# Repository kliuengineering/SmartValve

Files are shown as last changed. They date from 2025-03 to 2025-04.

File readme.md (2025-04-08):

# Smart Valve Shield for FRDM-K66F
- Authours
    - Amir
    - Kevin
    - Toan

## Preliminary Product Rendering
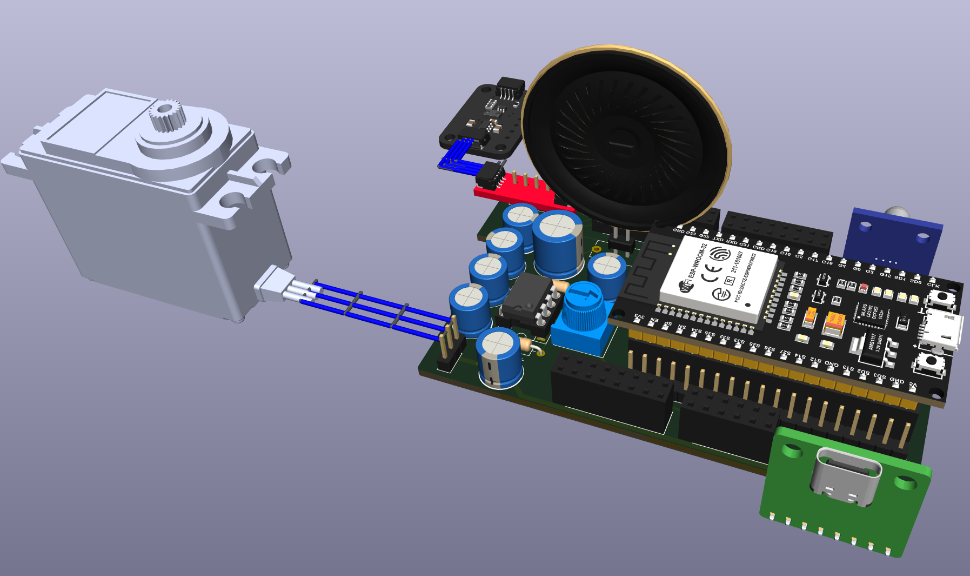
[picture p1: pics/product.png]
ProductImage


## Peripherals On the Shield
**Note: refer to the detailed BOM for specific components.**
1. USB-C power input
2. ESP32S module (38 pins)
3. Class AB amplifier
4. RGB LED module
5. Pressure sensor Qwiic adapter
6. Header pins for servo motor
7. Various pin sockets
8. Various passive components

## Hardware
The design is simple - we want to maximize the real estate of the shield so it becomes a sandbox tool for education purposes. The project about SmartValve is just a simple example of showing you its use case for education. To be fair - K66F is a development platform and is naive for commercial implementations.

### Circuits
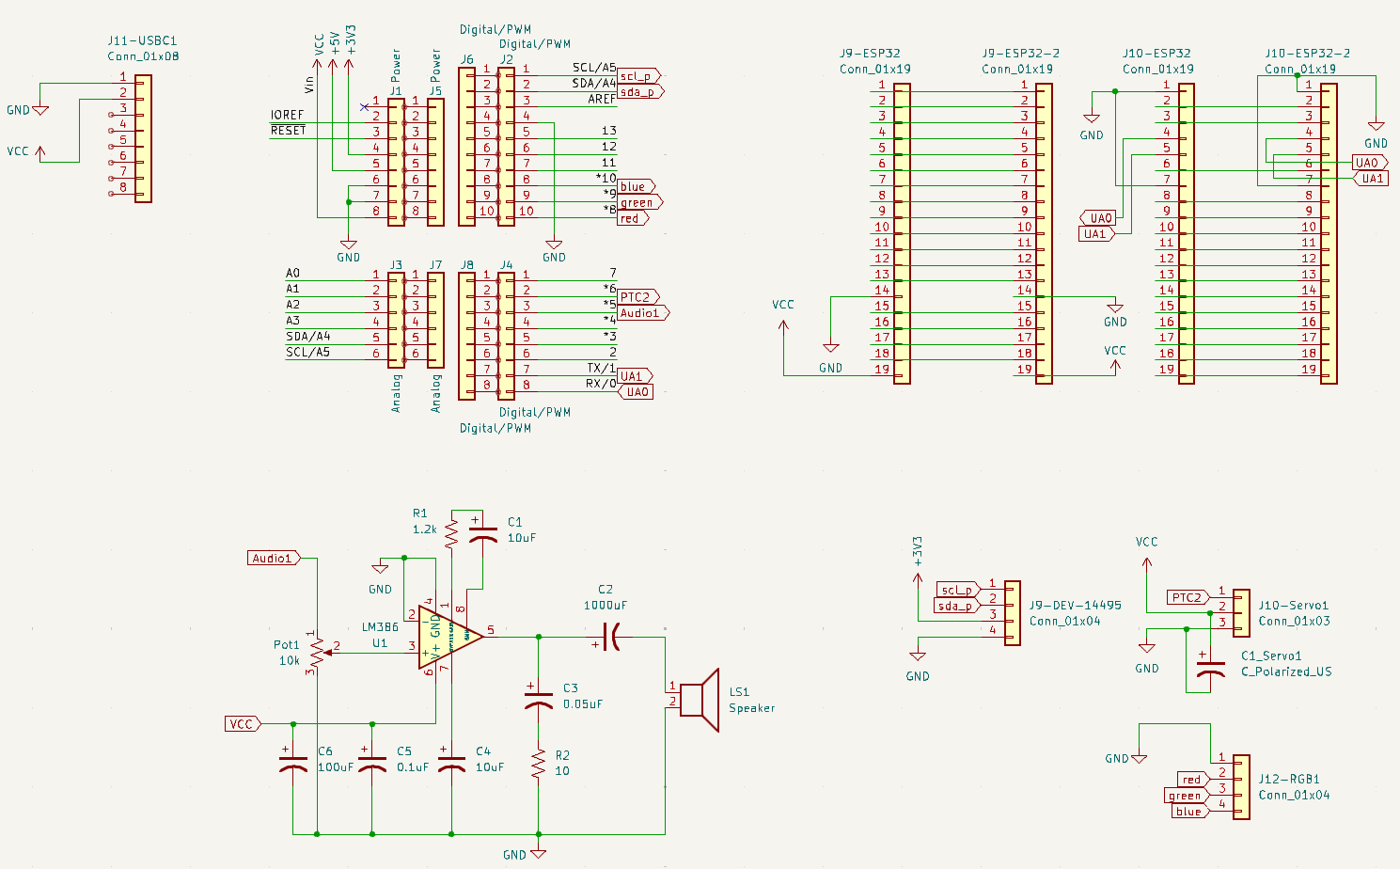
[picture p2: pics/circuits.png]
Circuits


### Routing
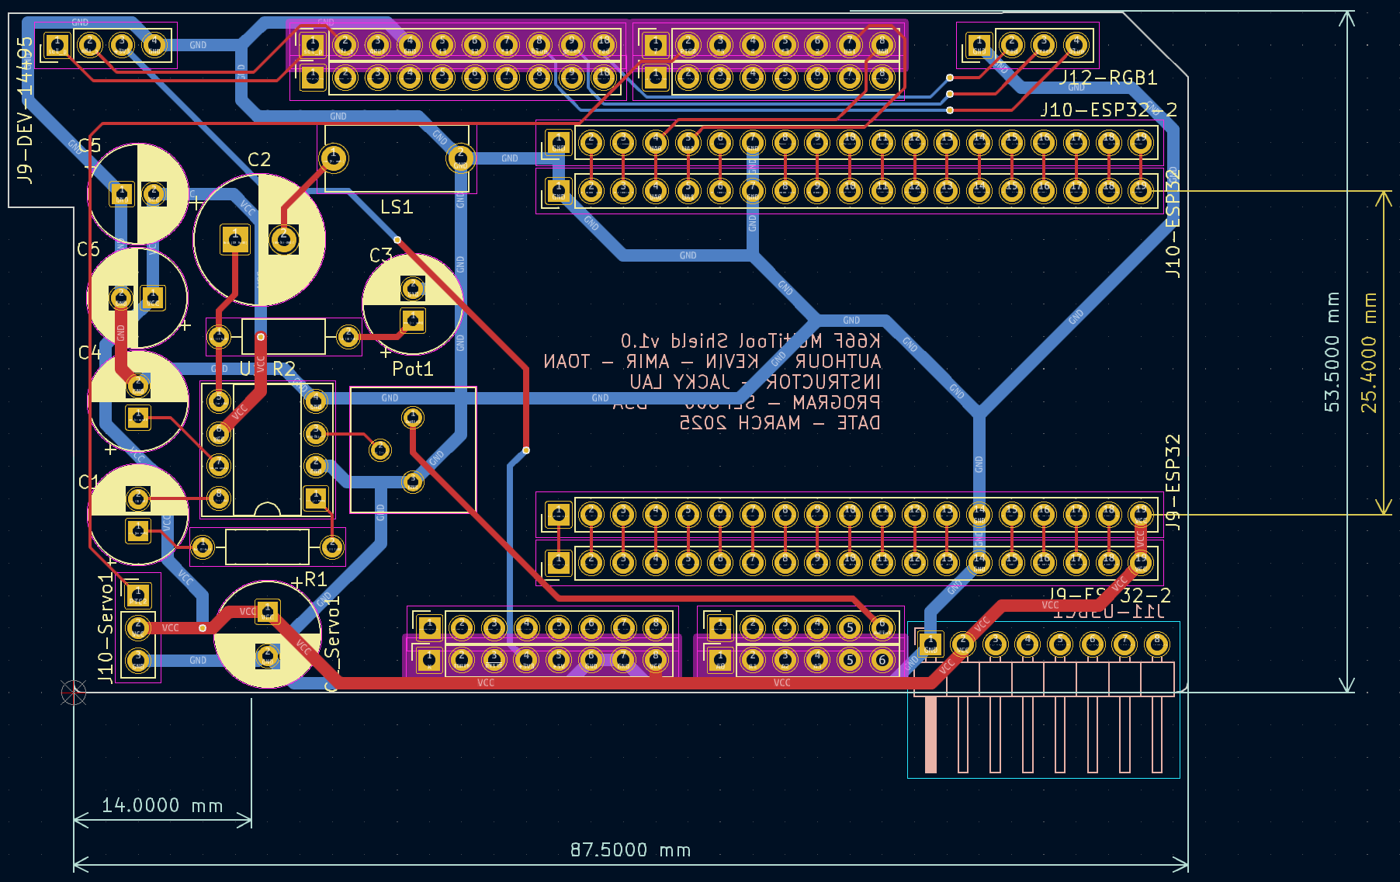
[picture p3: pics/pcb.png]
Routing


## Software

### Installations
1. If you are using Windows, then your machine may require an USB driver for the ESP32 MCU. You can download it here [USB Driver for Windows](Tools/CP210x_Universal_Windows_Driver.zip)

2. Follow the [ESP32 Markdown Documentation](./ESPServer/espserver.md) for server-side details.

### Data Logging Interface
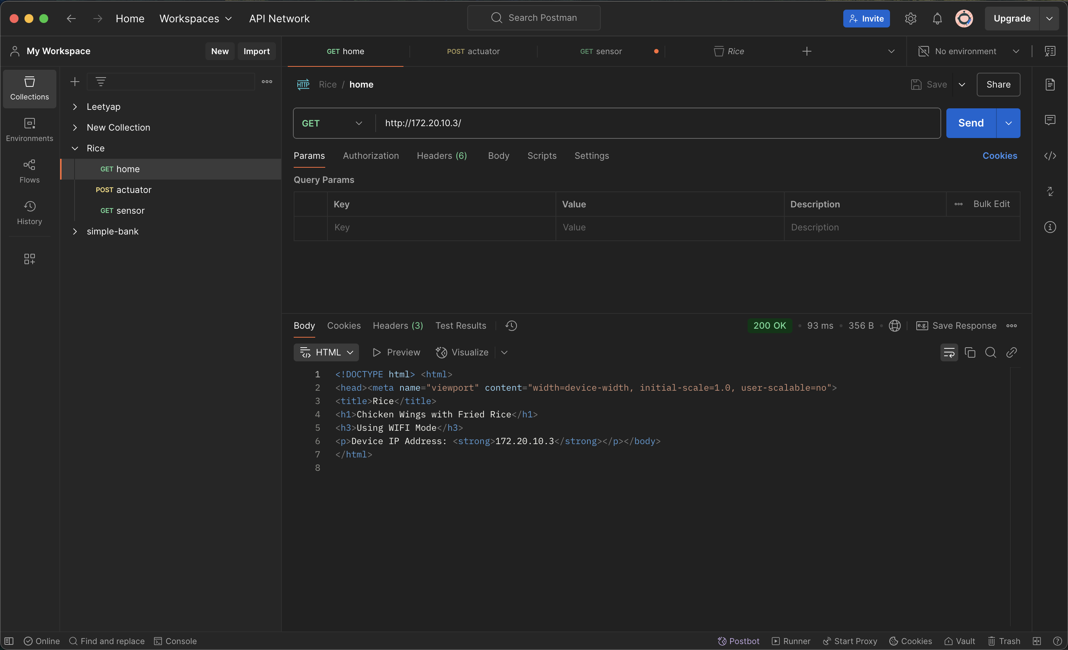
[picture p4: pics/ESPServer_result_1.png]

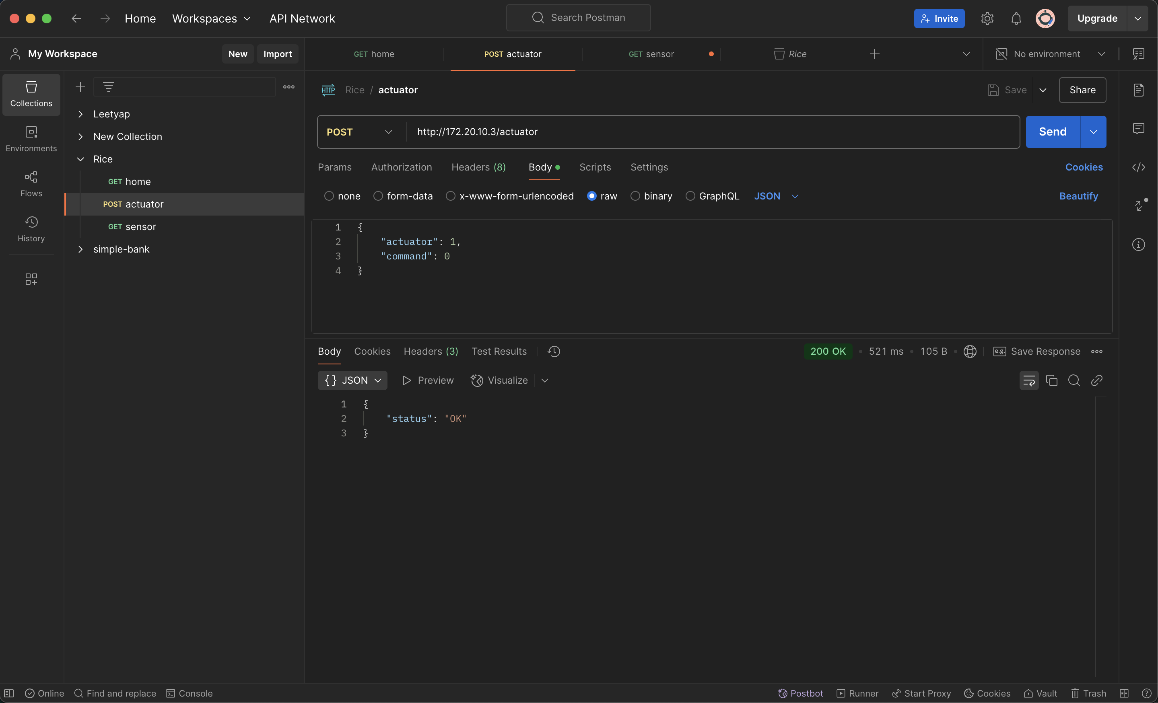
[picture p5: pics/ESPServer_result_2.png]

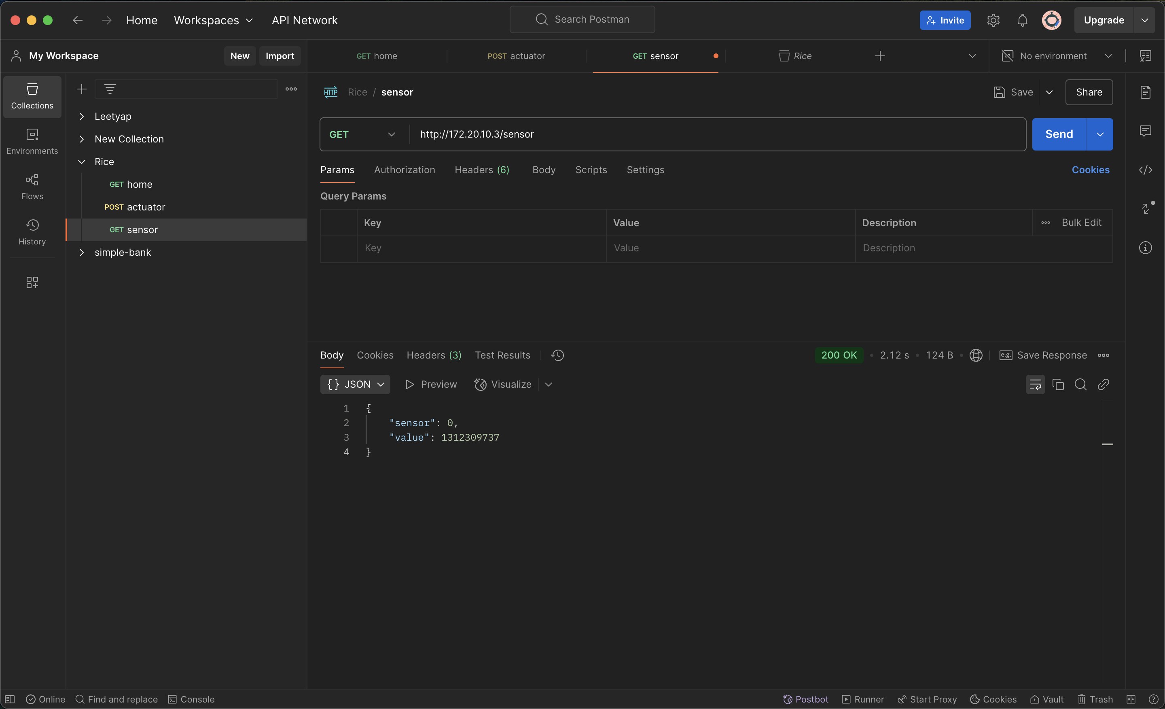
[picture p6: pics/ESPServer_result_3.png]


## Future Work
1. Exploring radio-frequency applications.
2. Implementing TinyML on ESP to carry out more mature edge computing.

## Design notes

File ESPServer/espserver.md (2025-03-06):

## ESP32 server

It acts like a bridge between clients and the K66F

## Hardware setup

#### Set up ESP32

1. Download and install Arduino IDE
2. Go to `Board Manager` -> install `esp32 by Espressif Systems`
3. Upload `espserver.ino` under ESPServer folder into the ESP32

#### Set up K66F

1. Open `Keil IDE`
2. Create a new project with an empty mbedOS project.
3. Copy `frdmk66.example.cpp` into `main.cpp`
4. Build the project into binary file
5. Drag and drop the binary file into the K66F

#### Set up hardware for both ESP32 and K66F (hardware)

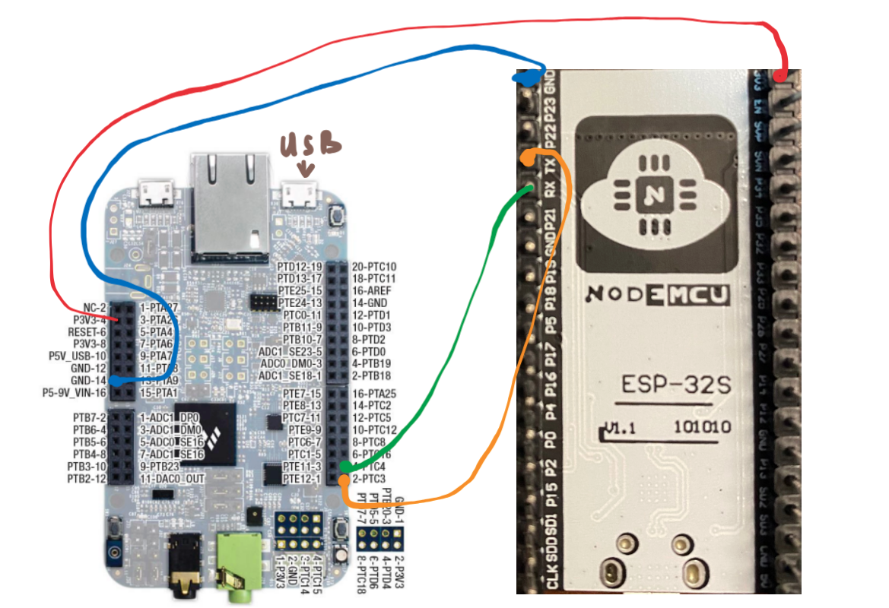
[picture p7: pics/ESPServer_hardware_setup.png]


#### Set up hardware for both ESP32 and K66F (software)

1. Connect K66F with your computer using USB cable
2. run

```bash
ls /dev/cu.* # or do whatever to find the port for K66F on your computer
screen /dev/cu.tty-14031 # dude, this port is mine, so put yours in here

Please press Enter to continue... # this is what we should see, so press Enter
```

3. This step is important, press EN button on ESP32 (maybe the RESET button). At the same time, we also have to turn `OFF` and then `ON` the Personal Hotspot on your phone. If you don't see it connecting with your Hotspot, wait for 1 second and repeat, and keep doing so until you see:

```bash
Please press Enter to continue...
K66F - Received ets Jul 29 2019 12:21:46

rst:0x1 (POWERON_RESET),boot:0x13 (SPI_FAST_FLASH_BOOT)
configsip: 0, SPIWP:0xee
clk_drv:0x00,q_d

K66F - Received rv:0x00,d_drv:0x00,cs0_drv:0x00,hd_drv:0x00,wp_drv:0x00
mode:DIO, clock div:1
load:0x3fff0030,len:4916
load:0x40078000,len:1

K66F - Received 64�

ESP - Connecting to tovn

K66F - Received ESP - WiFi Connected! IP Address: 172.20.10.3 # If you don't see this, keep doing step 3 until you see the IP Address. *Note: repeat after 1 or 2 seconds.
ESP - HTTP server started on port 80
```

## API endpoints

#### GET: /ip-address/

Inital request to be sure the ESP32 server is working.

```html
<!DOCTYPE html> <html>
<head><meta name="viewport" content="width=device-width, initial-scale=1.0, user-scalable=no">
<title>Rice</title>
<h1>Chicken Wings with Fried Rice</h1>
<h3>Using WIFI Mode</h3>
<p>Device IP Address: <strong>172.20.10.3</strong></p></body>
</html>
```

#### GET: /ip-address/sensor

Client requests sensor values from K66F via the ESP32 server.

```json
{
  "sensor": 1,
  "value": 12
}
```

#### POST: /ip-address/actuator

Client sends command to actuators attached to K66F via the ESP32 server.

```json
{
  "actuator": 1,
  "command": 0
}
```

## Expected results







```bash
Please press Enter to continue...
Please press Enter to continue...
K66F - Received ets Jul 29 2019 12:21:46

rst:0x1 (POWERON_RESET),boot:0x13 (SPI_FAST_FLASH_BOOT)
configsip: 0, SPIWP:0xee
clk_drv:0x00,q_d

K66F - Received rv:0x00,d_drv:0x00,cs0_drv:0x00,hd_drv:0x00,wp_drv:0x00
mode:DIO, clock div:1
load:0x3fff0030,len:4916
load:0x40078000,len:1

K66F - Received 64�

ESP - Connecting to tovn

K66F - Received ESP - WiFi Connected! IP Address: 172.20.10.3
ESP - HTTP server started on port 80

K66F - SENDDATA command received
K66F - send {"sensor": 0, "value": 1640049856}
K66F - Received SENDDATA

K66F - Received ESP - Received HTTP GET - /sensor

actuator command received
K66F - Received {
    "actuator": 1,
    "command": 0
}ESP - Received HTTP POST - /actuator
```

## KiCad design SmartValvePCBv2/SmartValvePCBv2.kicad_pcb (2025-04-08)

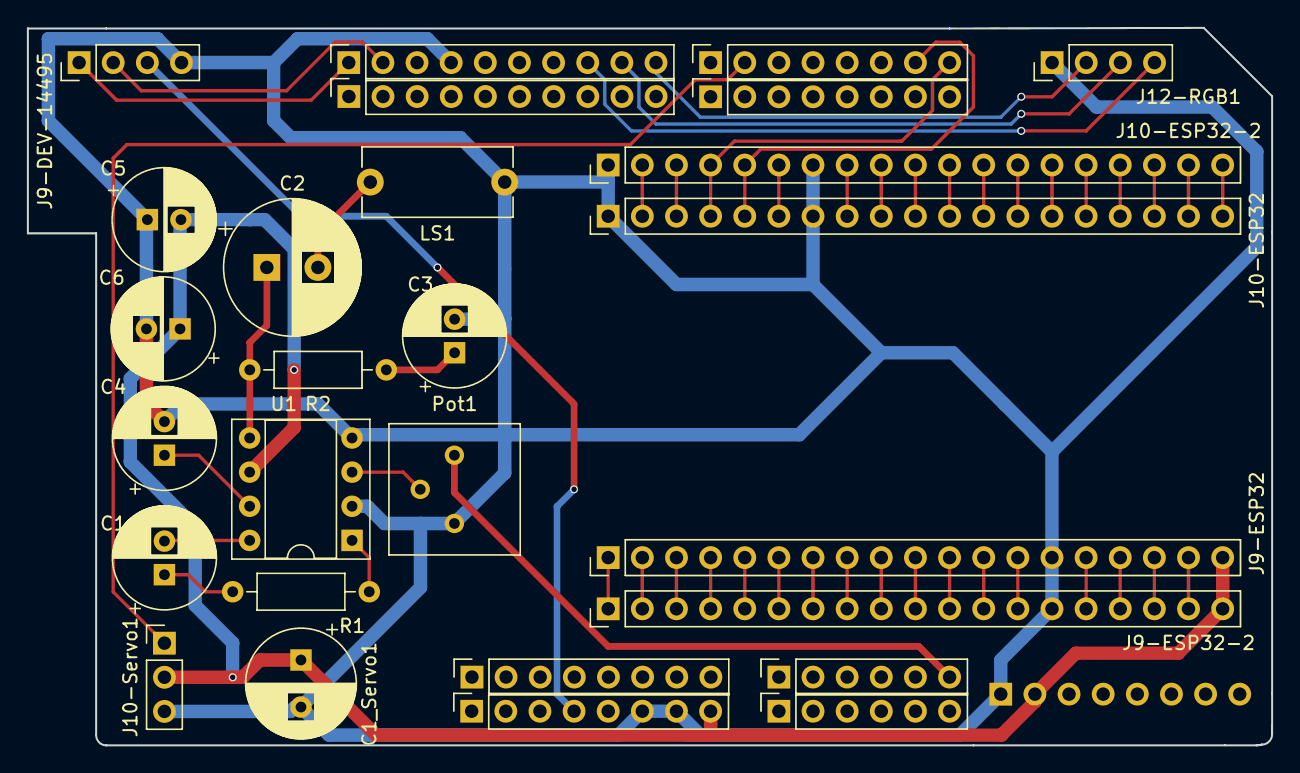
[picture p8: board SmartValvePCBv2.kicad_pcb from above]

Board: 2 copper layers, 92.6 x 53.4 mm, 28 parts (1 on the bottom side), 52 nets.

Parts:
C1, C4: 10uF; CP_Radial_D7.5mm_P2.50mm
C1_Servo1: C_Polarized_US; CP_Radial_D8.0mm_P3.50mm
C2: 470uF; CP_Radial_D10.0mm_P3.80mm
C3: 0.05uF; CP_Radial_D7.5mm_P2.50mm
C5: 0.1uF; CP_Radial_D7.5mm_P2.50mm
C6: 100uF; CP_Radial_D7.5mm_P2.50mm
J1, J5: Power; PinSocket_1x08_P2.54mm_Vertical
J2, J6: Digital/PWM; PinSocket_1x10_P2.54mm_Vertical
J3, J7: Analog; PinSocket_1x06_P2.54mm_Vertical
J4, J8: Digital/PWM; PinSocket_1x08_P2.54mm_Vertical
J9-DEV-14495, J12-RGB1: Conn_01x04; PinHeader_1x04_P2.54mm_Vertical
J9-ESP32, J9-ESP32-2, J10-ESP32, J10-ESP32-2: Conn_01x19; PinHeader_1x19_P2.54mm_Vertical
J10-Servo1: Conn_01x03; PinHeader_1x03_P2.54mm_Vertical
J11-USBC1: Conn_01x08; PinHeader_1x08_P2.54mm_Horizontal
LS1: Speaker; C_Disc_D11.0mm_W5.0mm_P10.00mm
Pot1: 10k; Potentiometer_Bourns_3386P_Vertical
R1: 1.2k; R_Axial_DIN0207_L6.3mm_D2.5mm_P10.16mm_Horizontal
R2: 10; R_Axial_DIN0207_L6.3mm_D2.5mm_P10.16mm_Horizontal
U1: LM386; DIP-8_W7.62mm_Socket

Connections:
+3V3: J1.4, J9-DEV-14495.3
Audio1: J7.6, Pot1.1
GND: C1_Servo1.2, C3.2, C4.2, C5.1, C6.2, J1.6, J1.7, J2.4, J9-DEV-14495.4, J9-ESP32.14, J9-ESP32-2.14, J10-ESP32.1, J10-ESP32.7, J10-ESP32-2.1, J10-ESP32-2.7, J10-Servo1.3, J11-USBC1.1, J12-RGB1.1, LS1.2, Pot1.3, U1.2 (-), U1.4 (GND)
unnamed: C1.1, R1.1
unnamed: C1.2, U1.8 (GAIN)
unnamed: C2.1, R2.1, U1.5
unnamed: C2.2, LS1.1
unnamed: C3.1, R2.2
unnamed: J9-ESP32.1, J9-ESP32-2.1
unnamed: J9-ESP32.2, J9-ESP32-2.2
unnamed: J9-ESP32.3, J9-ESP32-2.3
unnamed: J9-ESP32.4, J9-ESP32-2.4
unnamed: J9-ESP32.5, J9-ESP32-2.5
unnamed: J9-ESP32.6, J9-ESP32-2.6
unnamed: J9-ESP32.7, J9-ESP32-2.7
unnamed: J9-ESP32.8, J9-ESP32-2.8
unnamed: J9-ESP32.9, J9-ESP32-2.9
unnamed: J9-ESP32.10, J9-ESP32-2.10
unnamed: J9-ESP32.11, J9-ESP32-2.11
unnamed: J9-ESP32.12, J9-ESP32-2.12
unnamed: J9-ESP32.13, J9-ESP32-2.13
unnamed: J9-ESP32.15, J9-ESP32-2.15
unnamed: J9-ESP32.16, J9-ESP32-2.16
unnamed: J9-ESP32.17, J9-ESP32-2.17
unnamed: J9-ESP32.18, J9-ESP32-2.18
unnamed: J10-ESP32.2, J10-ESP32-2.2
unnamed: J10-ESP32.3, J10-ESP32-2.3
unnamed: J10-ESP32.6, J10-ESP32-2.6
unnamed: J10-ESP32.8, J10-ESP32-2.8
unnamed: J10-ESP32.9, J10-ESP32-2.9
unnamed: J10-ESP32.10, J10-ESP32-2.10
unnamed: J10-ESP32.11, J10-ESP32-2.11
unnamed: J10-ESP32.12, J10-ESP32-2.12
unnamed: J10-ESP32.13, J10-ESP32-2.13
unnamed: J10-ESP32.14, J10-ESP32-2.14
unnamed: J10-ESP32.15, J10-ESP32-2.15
unnamed: J10-ESP32.16, J10-ESP32-2.16
unnamed: J10-ESP32.17, J10-ESP32-2.17
unnamed: J10-ESP32.18, J10-ESP32-2.18
unnamed: J10-ESP32.19, J10-ESP32-2.19
unnamed: R1.2, U1.1 (GAIN)
unnamed: Pot1.2, U1.3 (+)
unnamed: C4.1, U1.7 (BYPASS)
PTC2: J4.2, J10-Servo1.1
UA0: J4.8, J10-ESP32.4, J10-ESP32-2.4
UA1: J4.7, J10-ESP32.5, J10-ESP32-2.5
VCC: C1_Servo1.1, C5.2, C6.1, J1.8, J9-ESP32.19, J9-ESP32-2.19, J10-Servo1.2, J11-USBC1.2, U1.6 (V+)
blue: J2.8, J12-RGB1.4
green: J2.9, J12-RGB1.3
red: J2.10, J12-RGB1.2
scl_p: J2.1, J9-DEV-14495.1
sda_p: J2.2, J9-DEV-14495.2

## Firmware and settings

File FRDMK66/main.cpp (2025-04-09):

#include "mbed.h"
#include "RGBLed.h"
#include "PressureSensor.h"
#include "ServoMotor.h"

using namespace std::chrono;

// --- Config ---
#define I2C_SDA_PIN PTC11
#define I2C_SCL_PIN PTC10
#define I2C_BAUDRATE 50000U
#define BMP3_I2C_ADDR 0x77
#define UART_TX PTC4
#define UART_RX PTC3
#define UART_BAUD 115200

// --- Interfaces ---
BufferedSerial uart(UART_TX, UART_RX, UART_BAUD);
I2C i2c(I2C_SDA_PIN, I2C_SCL_PIN);

// --- Devices ---
RGBLed led(PTB18, PTB19, PTD0);
PressureSensor sensor(i2c, BMP3_I2C_ADDR);
ServoMotor servo(PTC2);
bool valve_closed = false;

// --- Threads ---
Mutex lock_mutex;
Thread sensorThread;
Thread commsThread;

float pressure_hPa = 0.0f;

// --- Parse JSON command from ESP32 ---
bool parseActuatorCommand(const char* json, int& actuator, int& command) {
    const char* act_key = "\"actuator\"";
    const char* cmd_key = "\"command\"";
    const char* act_ptr = strstr(json, act_key);
    const char* cmd_ptr = strstr(json, cmd_key);
    if (!act_ptr || !cmd_ptr) return false;

    act_ptr = strchr(act_ptr, ':');
    cmd_ptr = strchr(cmd_ptr, ':');
    if (!act_ptr || !cmd_ptr) return false;

    actuator = atoi(++act_ptr);
    command = atoi(++cmd_ptr);

    return true;
}

// --- Read pressure sensor periodically ---
void read_sensor_data() {
    while (true) {
        float pressure = sensor.readPressure();
        lock_mutex.lock();
        pressure_hPa = pressure;
        printf("Pressure: %.2f hPa\n", pressure_hPa);
        lock_mutex.unlock();
        ThisThread::sleep_for(1s);
    }
}

// --- UART Command Handler (from ESP32) ---
void serve_client() {
    char buf[64];
    while (true) {
        if (uart.readable()) {
            uart.read(buf, sizeof(buf));
            buf[sizeof(buf) - 1] = '\0';

            if (strncmp(buf, "SENDDATA", 8) == 0) {
                lock_mutex.lock();
                char response[64];
                int len = sprintf(response, "{\"pressure\":%.2f}", pressure_hPa);
                uart.write(response, len);
                printf("Sent to ESP32: %s\n", response);
                lock_mutex.unlock();
            } 
            else if (strstr(buf, "actuator")) {
                int actuator, command;
                if (parseActuatorCommand(buf, actuator, command)) {
                    if (actuator == 1) {
                        if (command == 1 && !valve_closed) {
                            led.setColor(1.0, 0.0, 0.0);  // Red = Close
                            servo = 45.0f;
                            valve_closed = true;
                            printf("Valve CLOSED by AI command.\n");
                        } else if (command == 0 && valve_closed) {
                            led.setColor(0.0, 1.0, 0.0);  // Green = Open
                            servo = -45.0f;
                            valve_closed = false;
                            printf("Valve OPENED by AI command.\n");
                        }
                    }
                } else {
                    printf("Failed to parse actuator command.\n");
                }
            }
        }
        ThisThread::sleep_for(100ms);
    }
}

// --- Entry Point ---
int main() {
    printf("FRDM-K66 Booting...\n");

    i2c.frequency(I2C_BAUDRATE);
    led.setColor(0.0, 0.0, 0.0);  // LED OFF on boot
    sensor.initialize();

    sensorThread.start(read_sensor_data);
    commsThread.start(serve_client);

    while (true) {
        ThisThread::sleep_for(1s);
    }
}

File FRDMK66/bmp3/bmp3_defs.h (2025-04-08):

/**
* Copyright (c) 2022 Bosch Sensortec GmbH. All rights reserved.
*
* BSD-3-Clause
*
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
* 1. Redistributions of source code must retain the above copyright
*    notice, this list of conditions and the following disclaimer.
*
* 2. Redistributions in binary form must reproduce the above copyright
*    notice, this list of conditions and the following disclaimer in the
*    documentation and/or other materials provided with the distribution.
*
* 3. Neither the name of the copyright holder nor the names of its
*    contributors may be used to endorse or promote products derived from
*    this software without specific prior written permission.
*
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
* @file       bmp3_defs.h
* @date       2022-04-01
* @version    v2.0.6
*
*/

/*! @file bmp3_defs.h
 * @brief Sensor driver for BMP3 sensor */

 #ifndef BMP3_DEFS_H_
 #define BMP3_DEFS_H_
 
 /*! CPP guard */
 #ifdef __cplusplus
 extern "C" {
 #endif
 
 /********************************************************/
 /* header includes */
 #ifdef __KERNEL__
 #include <linux/types.h>
 #include <linux/kernel.h>
 #else
 #include <stdint.h>
 #include <stddef.h>
 #endif
 
 /*************************** Common macros   *****************************/
 
 #if !defined(UINT8_C) && !defined(INT8_C)
 #define INT8_C(x)    S8_C(x)
 #define UINT8_C(x)   U8_C(x)
 #endif
 
 #if !defined(UINT16_C) && !defined(INT16_C)
 #define INT16_C(x)   S16_C(x)
 #define UINT16_C(x)  U16_C(x)
 #endif
 
 #if !defined(INT32_C) && !defined(UINT32_C)
 #define INT32_C(x)   S32_C(x)
 #define UINT32_C(x)  U32_C(x)
 #endif
 
 #if !defined(INT64_C) && !defined(UINT64_C)
 #define INT64_C(x)   S64_C(x)
 #define UINT64_C(x)  U64_C(x)
 #endif
 
 /**@}*/
 /**\name C standard macros */
 #ifndef NULL
 #ifdef __cplusplus
 #define NULL         0
 #else
 #define NULL         ((void *) 0)
 #endif
 #endif
 
 #ifndef TRUE
 #define TRUE         UINT8_C(1)
 #endif
 
 #ifndef FALSE
 #define FALSE        UINT8_C(0)
 #endif
 
 /********************************************************/
 /**\name Compiler switch macros */
 
 #ifndef BMP3_64BIT_COMPENSATION /*< Check if 64bit (using BMP3_64BIT_COMPENSATION) is enabled */
 #ifndef BMP3_FLOAT_COMPENSATION /*< If 64 bit integer data type is not enabled then enable
                                             * BMP3_FLOAT_COMPENSATION */
 #define BMP3_FLOAT_COMPENSATION
 #endif
 #endif
 
 /********************************************************/
 /**\name Macro definitions */
 
 /**
  * BMP3_INTF_RET_TYPE is the read/write interface return type which can be overwritten by the build system.
  */
 #ifndef BMP3_INTF_RET_TYPE
 #define BMP3_INTF_RET_TYPE                      int8_t
 #endif
 
 /**
  * The last error code from read/write interface is stored in the device structure as intf_rslt.
  */
 #ifndef BMP3_INTF_RET_SUCCESS
 #define BMP3_INTF_RET_SUCCESS                   INT8_C(0)
 #endif
 
 /**\name I2C addresses */
 #define BMP3_ADDR_I2C_PRIM                      UINT8_C(0x76)
 #define BMP3_ADDR_I2C_SEC                       UINT8_C(0x77)
 
 /**\name BMP3 chip identifier */
 #define BMP3_CHIP_ID                            UINT8_C(0x50)
 #define BMP390_CHIP_ID                          UINT8_C(0x60)
 
 /**\name BMP3 pressure settling time (micro secs)*/
 #define BMP3_SETTLE_TIME_PRESS                  UINT16_C(392)
 
 /**\name BMP3 temperature settling time (micro secs) */
 #define BMP3_SETTLE_TIME_TEMP                   UINT16_C(313)
 
 /**\name BMP3 adc conversion time (micro secs) */
 #define BMP3_ADC_CONV_TIME                      UINT16_C(2000)
 
 /**\name Register Address */
 #define BMP3_REG_CHIP_ID                        UINT8_C(0x00)
 #define BMP3_REG_ERR                            UINT8_C(0x02)
 #define BMP3_REG_SENS_STATUS                    UINT8_C(0x03)
 #define BMP3_REG_DATA                           UINT8_C(0x04)
 #define BMP3_REG_EVENT                          UINT8_C(0x10)
 #define BMP3_REG_INT_STATUS                     UINT8_C(0x11)
 #define BMP3_REG_FIFO_LENGTH                    UINT8_C(0x12)
 #define BMP3_REG_FIFO_DATA                      UINT8_C(0x14)
 #define BMP3_REG_FIFO_WM                        UINT8_C(0x15)
 #define BMP3_REG_FIFO_CONFIG_1                  UINT8_C(0x17)
 #define BMP3_REG_FIFO_CONFIG_2                  UINT8_C(0x18)
 #define BMP3_REG_INT_CTRL                       UINT8_C(0x19)
 #define BMP3_REG_IF_CONF                        UINT8_C(0x1A)
 #define BMP3_REG_PWR_CTRL                       UINT8_C(0x1B)
 #define BMP3_REG_OSR                            UINT8_C(0X1C)
 #define BMP3_REG_ODR                            UINT8_C(0x1D)
 #define BMP3_REG_CONFIG                         UINT8_C(0x1F)
 #define BMP3_REG_CALIB_DATA                     UINT8_C(0x31)
 #define BMP3_REG_CMD                            UINT8_C(0x7E)
 
 /**\name Error status macros */
 #define BMP3_ERR_FATAL                          UINT8_C(0x01)
 #define BMP3_ERR_CMD                            UINT8_C(0x02)
 #define BMP3_ERR_CONF                           UINT8_C(0x04)
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

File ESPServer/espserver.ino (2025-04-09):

#include <WiFi.h>
#include <WebServer.h>
#include <ArduinoJson.h>
#include "NeuralNetwork.h"

// WiFi Credentials
const char* ssid = "Amir";
const char* password = "gotthat1";

// IP Configuration
IPAddress local_IP(172, 20, 10, 3);
IPAddress gateway(172, 20, 10, 1);
IPAddress subnet(255, 255, 255, 0);

// Web Server
WebServer server(80);

// Sensor/Actuator and Gradient Tracking
float prevPressure = 0.0;
unsigned long prevTime = 0;

// AI Model
NeuralNetwork model(3);
InputLayer input(1);
DenseLayer hidden(4, ActivationKind::Relu);
OutputLayer output(1, ActivationKind::Sigmoid);

// Function Prototypes
void on_connect_handler();
void sensor_handler();
void actuator_handler();
void not_found_handler();
String SendHTML(String st);
String requestK66FData();
float performPressureGradient(float currentPressure, float previousPressure, float dt);
void sendActuatorCommand(int actuator, int command);
void sensorTask(void * parameters);

void setup() {
  Serial.begin(115200);
  pinMode(5, OUTPUT);

  WiFi.config(local_IP, gateway, subnet);
  WiFi.begin(ssid, password);
  while (WiFi.status() != WL_CONNECTED) {
    delay(500);
    Serial.print(".");
  }
  digitalWrite(5, LOW);
  Serial.println("\nESP - WiFi Connected!");

  // Web routes
  server.on("/", HTTP_GET, on_connect_handler);
  server.on("/sensor", HTTP_GET, sensor_handler);
  server.on("/actuator", HTTP_POST, actuator_handler);
  server.onNotFound(not_found_handler);
  server.begin();

  // Build AI model
  model.StackLayer(&input).StackLayer(&hidden).StackLayer(&output);
  model.Build();
  // TODO: Hardcode trained weights and biases here

  // Start Sensor Task
  xTaskCreatePinnedToCore(sensorTask, "SensorTask", 10000, NULL, 1, NULL, 0);
}

void loop() {
  server.handleClient();
}

void on_connect_handler() {
  server.send(200, "text/html", SendHTML(WiFi.localIP().toString()));
}

void sensor_handler() {
  String response = requestK66FData();
  server.send(200, "application/json", response);
}

void actuator_handler() {
  if (!server.hasArg("plain")) {
    server.send(400, "text/plain", "Bad request: Body is empty");
    return;
  }
  String body = server.arg("plain");
  Serial.write(body.c_str());
  server.send(200, "application/json", "{\"status\":\"OK\"}");
}

void not_found_handler() {
  server.send(404, "text/plain", "{\"error\":\"Not Found\"}");
}

String SendHTML(String st) {
  return "<!DOCTYPE html><html><head><meta name='viewport' content='width=device-width, initial-scale=1.0'><title>Flood Monitor</title></head><body><h1>Flood Monitoring System</h1><p>IP Address: <strong>" + st + "</strong></p></body></html>";
}

String requestK66FData() {
  Serial.write("SENDDATA");
  delay(1000);
  char response[128];
  size_t bytesRead = 0;
  if (Serial.available() > 0) {
    bytesRead = Serial.readBytes(response, sizeof(response) - 1);
  }
  response[bytesRead] = '\0';
  return String(response);
}

float performPressureGradient(float currentPressure, float previousPressure, float dt) {
  return (dt > 0) ? (currentPressure - previousPressure) / dt : 0;
}

void sendActuatorCommand(int actuator, int command) {
  String cmd = "{\"actuator\":" + String(actuator) + ", \"command\":" + String(command) + "}";
  Serial.println(cmd);
  Serial.write(cmd.c_str());
}

void sensorTask(void * parameters) {
  for (;;) {
    unsigned long currentTime = millis();
    String response = requestK66FData();

    StaticJsonDocument<256> doc;
    DeserializationError error = deserializeJson(doc, response);
    float currentPressure = 0.0;
    if (!error) {
      currentPressure = doc["pressure"];
    } else {
      Serial.println("Failed to parse pressure JSON");
    }

    if (prevTime > 0) {
      float dt = (currentTime - prevTime) / 1000.0;
      float gradient = performPressureGradient(currentPressure, prevPressure, dt);
      Serial.print("Gradient: "); Serial.println(gradient);

      float inputVals[1] = {gradient};
      float* result = model.Predict(inputVals, 1);

      if (result[0] > 0.7) {
        sendActuatorCommand(1, 1); // High risk - close valve
      } else if (result[0] < 0.3) {
        sendActuatorCommand(1, 0); // Low risk - open valve
      }
    }

    prevPressure = currentPressure;
    prevTime = currentTime;
    delay(500);
  }
}

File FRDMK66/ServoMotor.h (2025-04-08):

#ifndef __SERVOMOTOR_H__
#define __SERVOMOTOR_H__

#include "mbed.h"

#define SERVO_CENTER_PULSE  0.0015f     // 1.5ms for neutral (center)
#define SERVO_MIN_PULSE     0.0011f     // 1.1ms for -45 degrees
#define SERVO_MAX_PULSE     0.0019f     // 1.9ms for +45 degrees
#define SERVO_PERIOD        0.020f      // 20ms period (50Hz)

class ServoMotor
{
private:
    PwmOut  servo;
    float   angle;

    void setServoAngle (void)
    {
        if (angle < -45.0f) angle = -45.0f;
        if (angle >  45.0f) angle =  45.0f;

        // Convert angle (-45° to +45°) to pulse width (1.1ms to 1.9ms)
        float pulse_width = SERVO_CENTER_PULSE + 
                            ((angle / 45.0f) * 
                            (SERVO_MAX_PULSE - SERVO_CENTER_PULSE));

        servo.pulsewidth(pulse_width);
    }

public:
    ServoMotor  (PinName pin) : 
    servo       (pin),
    angle       (0.0f)
    {
        servo.period(SERVO_PERIOD);
        setServoAngle();
    }

    void operator= (const float &new_angle)
    {
        if (angle != new_angle)
        {
            angle = new_angle;
            setServoAngle();
        }
    }
};

#endif

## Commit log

2025-03-06 added sample code for k66f and esp32 server
2025-03-06 fixed the picture urls and added something to espserver.md
    [frdmk66.example.cpp]
2025-03-19 New landing page for HTTP server
2025-04-06 added usb driver tool.
2025-04-08 added hardware folder; added md documentation.
    [SmartValvePCBv2-B_Cu.gbr, SmartValvePCBv2-B_Fab.gbr, SmartValvePCBv2-B_Mask.gbr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]
2025-04-09 Fixed bugs in K66 code
    [main.cpp]
